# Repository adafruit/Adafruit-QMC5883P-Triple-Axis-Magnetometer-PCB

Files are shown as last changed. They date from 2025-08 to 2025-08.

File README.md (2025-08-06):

## Adafruit QMC5883P - Triple Axis Magnetometer - STEMMA QT PCB

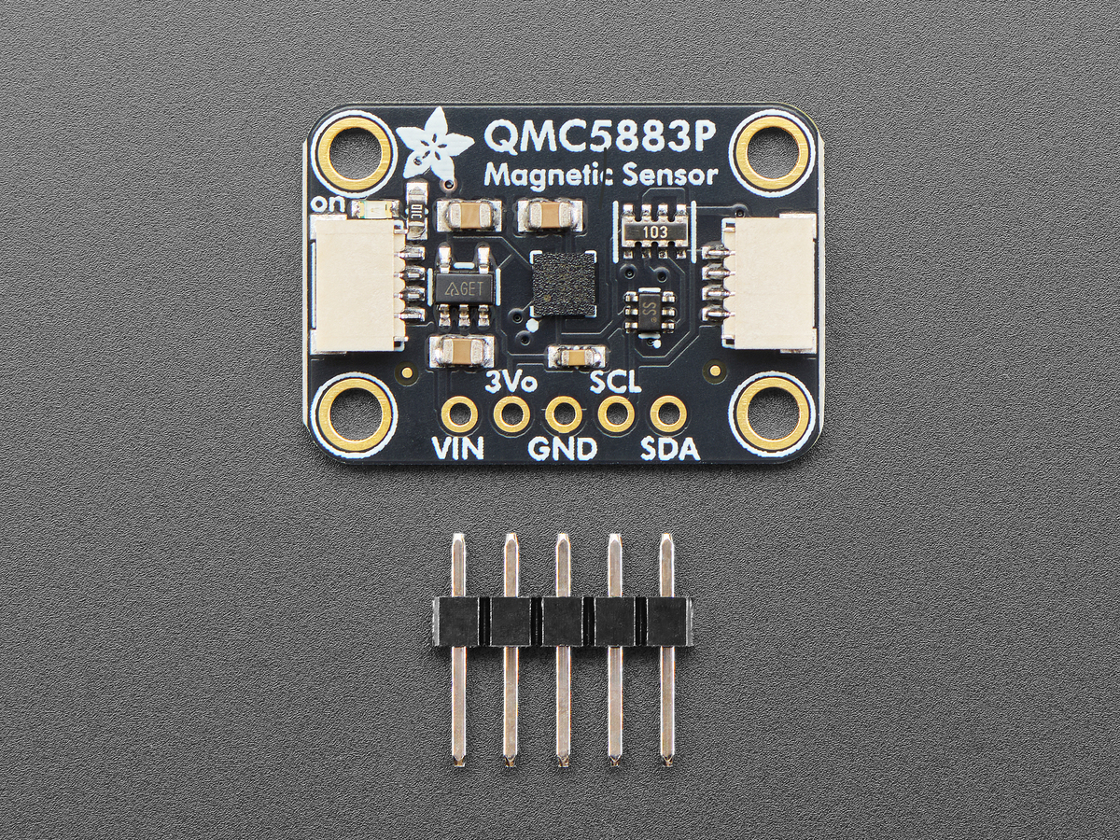
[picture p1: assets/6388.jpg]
<a href="http://www.adafruit.com/products/6388"><br/>
Click here to purchase one from the Adafruit shop</a>

PCB files for the Adafruit QMC5883P - Triple Axis Magnetometer - STEMMA QT. 

Format is EagleCAD schematic and board layout
* https://www.adafruit.com/product/6388

### Description

Sense the magnetic fields that surround us with this handy triple-axis magnetometer (compass) module. Magnetometers can sense where the strongest magnetic force is coming from, generally used to detect magnetic north, but can also be used for measuring magnetic fields. This sensor tends to be paired with a 6-DoF (degree of freedom) accelerometer/gyroscope to create a 9-DoF inertial measurement unit that can detect its orientation in real-space thanks to Earth's stable magnetic field.

We based this breakout on the QMC5883P, a magnetometer we see used in may Quadcopter and robotic builds. This compact sensor uses I2C to communicate, and it's very easy to use. Simply download our library and connect the SCL pin to your I2C clock pin, and SDA pin to your I2C data pin and upload our test program to read out magnetic field data.

This sensor can sense ranges from +-2 Gauss (+- 200 uTesla) up to +-30 gauss (+- 3000 uT or 3.0 mT). With 16-bit ADC and settings for over-sampling and down-sampling, you can set it up to get just the right range and precision.

To make life easier so you can focus on your important work, we've taken the QMC5883P and put it onto a breakout PCB along with support circuitry to let you use this little wonder with 3.3V (Feather/Raspberry Pi) or 5V (Arduino/ Metro328) logic levels. Additionally, since it speaks I2C you can easily connect it up with two wires (plus power and ground!).  We've even included SparkFun qwiic compatible STEMMA QT connectors for the I2C bus so you don't even need to solder! Just wire up to your favorite micro and you can use our CircuitPython/Python or Arduino drivers to easily interface with the QMC5883P and get magnetic measurements ASAP. QT Cable is not included, but we have a variety in the shop. 

It's fully assembled and tested.  Comes with a bit of 0.1" standard header in case you want to use it with a breadboard or perfboard.  Four 2.5mm (0.1") mounting holes for easy attachment.

### License

Adafruit invests time and resources providing this open source design, please support Adafruit and open-source hardware by purchasing products from [Adafruit](https://www.adafruit.com)!

Designed by Limor Fried/Ladyada for Adafruit Industries.

Creative Commons Attribution/Share-Alike, all text above must be included in any redistribution. 
See license.txt for additional details.

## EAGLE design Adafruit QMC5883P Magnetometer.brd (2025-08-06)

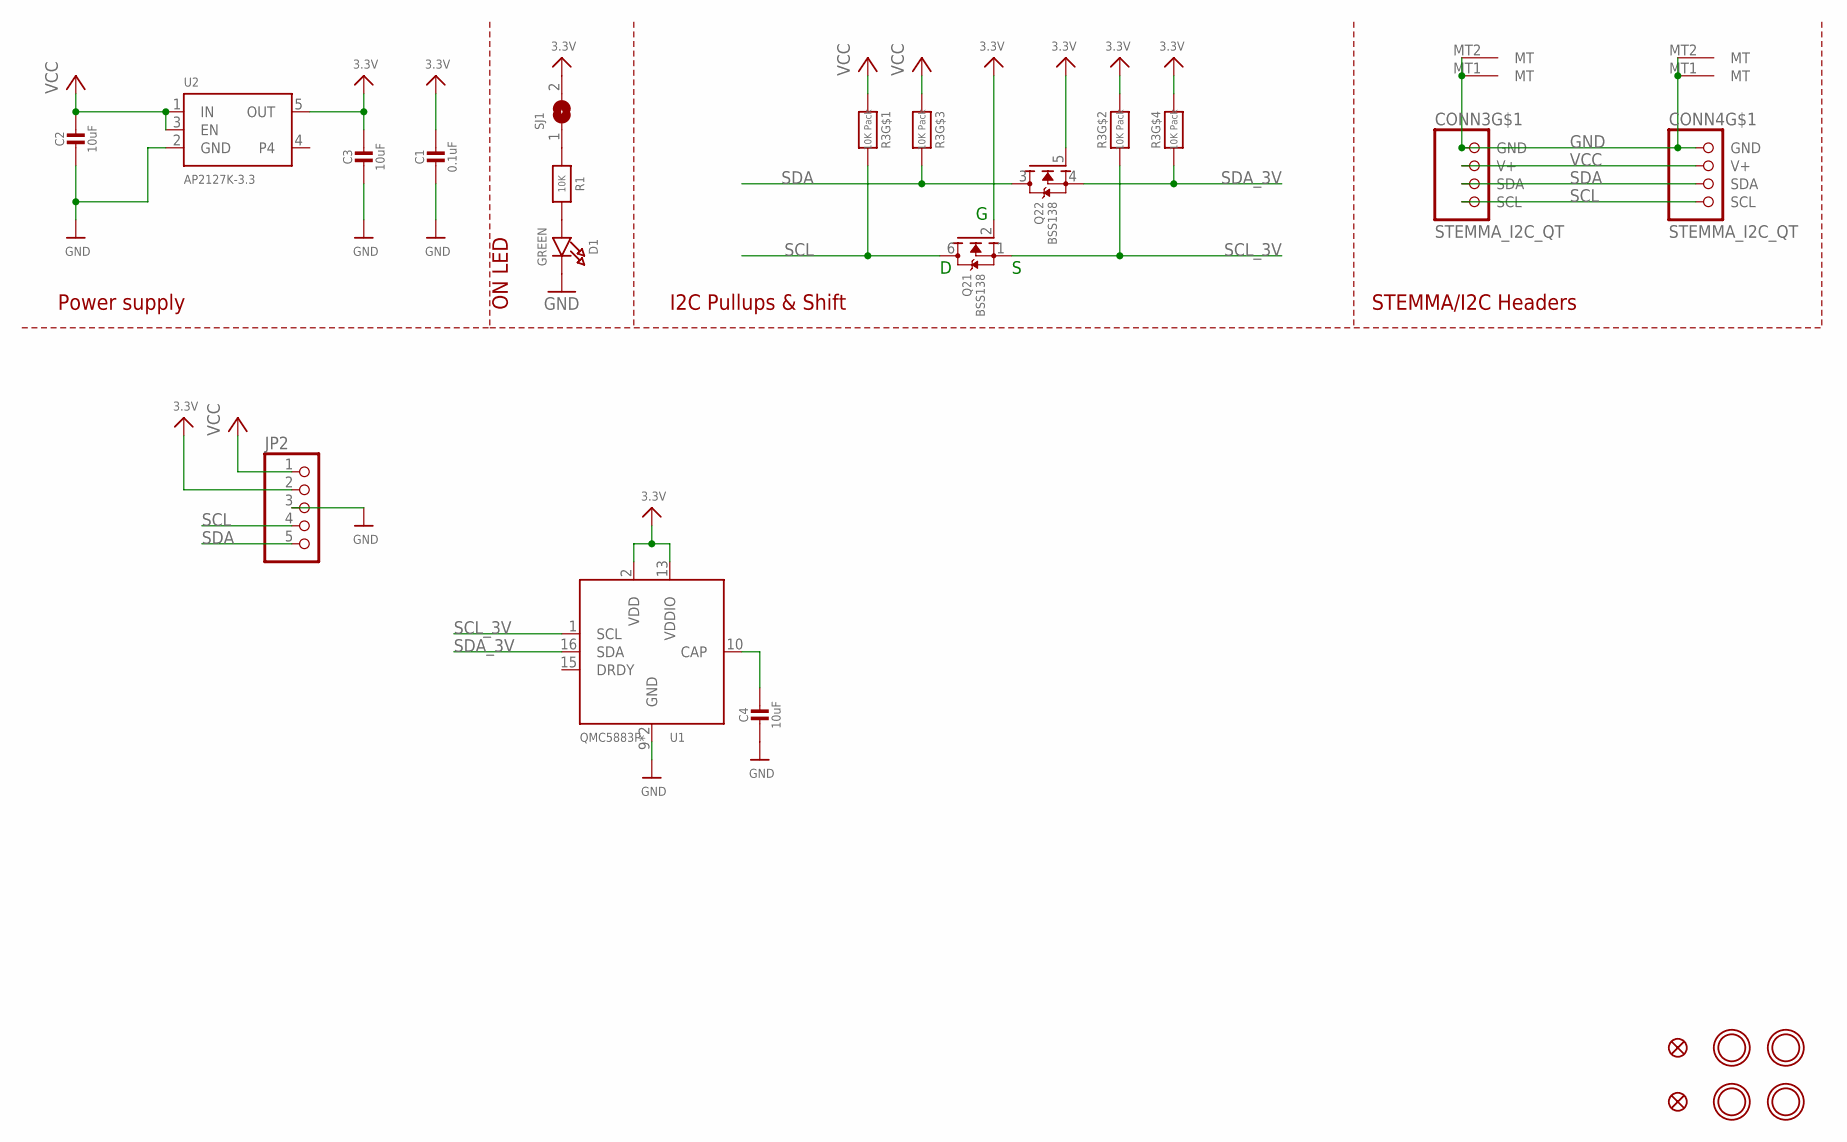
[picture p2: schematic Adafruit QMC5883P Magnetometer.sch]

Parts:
C1: 0.1uF; 0603-NO
C2, C3, C4: 10uF; 0805-NO
CONN3, CONN4: STEMMA_I2C_QT; JST_SH4
D1: GREEN; CHIPLED_0603_NOOUTLINE
FID3, FID4: FIDUCIAL_0.5MM
JP2: HEADER-1X570MIL; 1X05_ROUND_70
Q2: BSS138; SOT363
R1: 10K; 0603-NO
R3: 10K Pack; RESPACK_4X0603
SJ1: SOLDERJUMPERCLOSED; SOLDERJUMPER_CLOSEDWIRE
U1: QMC5883P; HMC5883L
U2: AP2127K-3.3; SOT23-5
U$1, U$17, U$19, U$21: MOUNTINGHOLE2.5; MOUNTINGHOLE_2.5_PLATED

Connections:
3.3V: C1.1, C3.1, JP2.2, Q2.2 (G), Q2.5 (G), R3.2 (1), R3.4 (1), SJ1.2, U1.2 (VDD), U1.13 (VDDIO), U2.5 (OUT)
GND: C1.2, C2.2, C3.2, C4.2, CONN3.1 (GND), CONN3.MT1 (MT), CONN3.MT2 (MT), CONN4.1 (GND), CONN4.MT1 (MT), CONN4.MT2 (MT), D1.C, JP2.3, U1.9 (GND), U1.11 (GND), U2.2 (GND)
unnamed: D1.A, R1.2
unnamed: R1.1, SJ1.1
unnamed: C4.1, U1.10 (CAP)
SCL: CONN3.4 (SCL), CONN4.4 (SCL), JP2.4, Q2.6 (D), R3.8 (2)
SCL_3V: Q2.1 (S), R3.7 (2), U1.1 (SCL)
SDA: CONN3.3 (SDA), CONN4.3 (SDA), JP2.5, Q2.3 (D), R3.6 (2)
SDA_3V: Q2.4 (S), R3.5 (2), U1.16 (SDA)
VCC: C2.1, CONN3.2 (V+), CONN4.2 (V+), JP2.1, R3.1, R3.3 (1), U2.1 (IN), U2.3 (EN)

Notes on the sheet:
I2C Pullups & Shift
STEMMA/I2C Headers
ON LED
Power supply

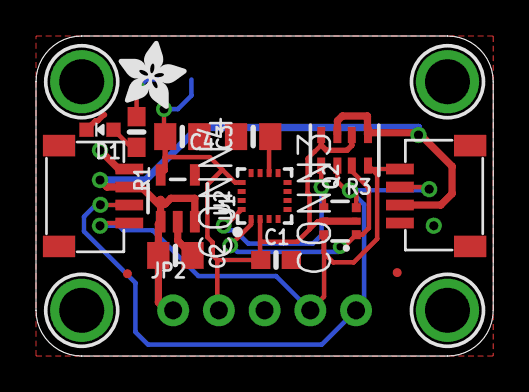
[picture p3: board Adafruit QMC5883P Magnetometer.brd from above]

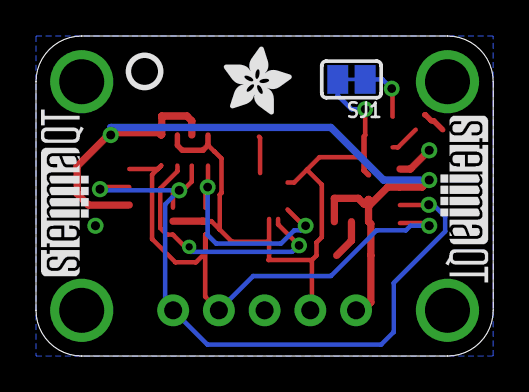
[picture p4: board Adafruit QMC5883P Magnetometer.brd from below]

Board: 2 copper layers, 25.4 x 17.8 mm, 37 parts (9 on the bottom side), 10 nets.

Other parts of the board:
PLABEL0: PLABEL0
PLABEL1: PLABEL1
PLABEL2: PLABEL2
PLABEL3: PLABEL3
PLABEL4: PLABEL4
PLABEL5: PLABEL5
PLABEL6: PLABEL6
PLABEL7: PLABEL7
PLABEL8: PLABEL8
PLABEL10: PLABEL10
PLABEL11: PLABEL11
PLABEL12: PLABEL12
U$9, U$22: ADAFRUIT_3.5MM
U$25: PCBFEAT-REV-040
U$30, U$31: STEMMAQT

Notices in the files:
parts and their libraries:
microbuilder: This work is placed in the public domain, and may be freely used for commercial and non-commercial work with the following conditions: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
